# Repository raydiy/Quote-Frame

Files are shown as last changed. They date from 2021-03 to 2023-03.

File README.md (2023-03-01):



# QUOTEFRAME / SPRYGGKLOPPA

This is the complete repository for RAYDIY's QUOTEFRAME (in Germany it's called SPRYGGKLOPPA) project.  
It includes all the 3D printing files and code needed to build this digital quote frame.

More informations here: https://raydiy.de/spryggkloppa-digitaler-spruechekalender/

## Features

- display a set of quotes, sayings, motivationals etc. on an ePaper driven display
- let the displayed text change at an interval you like (every X seconds or minutes or hours or days)
- the quotes are automatically formatted to fit on the screen
- a random font is used to display the quotes
- random font sizes are used to make the quotes more diverse and more appealing
- can be powered with batteries
- config mode is started via touch on a touch sensor
- config mode start a WiFi access point – jus log in an do your changes in the settings

**In config mode you can:**

- add/edit/delete quotes
- export and import the quotes with a JSON format (for backups or bigger edits)
- change the language for the config mode
- change the quote change interval from X seconds to X days

## Updates

#### v1.60 
**Attention:** If you are updating: for this update you will need to re-upload the html files in the data folder to SPIFFS file system.
This will erase your quotes! Because the quotes are also saved in the SPIFFS files system! 
You can export your quotes to JSON **BEFORE** you upload the new code. After the new version is installed you can import this JSON in config mode back into the frame.

- NEW: replaced current fonts with u8g2 font system
- NEW: three Google Fonts converted to u8g2 compatible format and added to project
- NEW: added support for special characters like german ÄÖÜ (due to u8g2)
- NEW: added localization for german language, you can select the language in the settings screen
- ENHANCED: the touch sensor can now be used to restart the frame from config mode back into normal mode
- ENHANCED: fall back font for long quotes. If quotes are longer than 90 symbols, the used font will always be the space saving BebasNeue to ensure it fits on the screen.

#### v1.51 first official release

## 3rd Party Resources

The following third party resources are used. Thank you!

- [GxEPD2 Library by ZinggJM](https://github.com/ZinggJM/GxEPD2)
- [ESP Async WebServer by Hristo Gochkov](https://github.com/me-no-dev/ESPAsyncWebServer.git)
- [ArduinoJson by Benoit Blanchon](https://github.com/bblanchon/ArduinoJson)
- [U8g2_for_Adafruit_GFX by Oliver Kraus](https://github.com/olikraus/U8g2_for_Adafruit_GFX.git)
- [Google Fonts Project](https://fonts.google.com/)
- [mini.css by Angelos Chalaris](https://minicss.org/)

## Project Folders

The following folders are in the download archive:

- **QuoteFrameCode/**: PlatformIO project folder, contains the software for the esp32 microcontroller
- **FreeCAD/**: contains all FreeCAD files for the display mount and the frame
- **Fusion360/**: contains the Fusion 360 archive for the display mount and the frame
- **STL/**: contains the exported ready-to-print STL files from the Fusion 360 project.

## Assembling Instructions (german language only, yet)

Currently there is only a german video instruction. 

ASSEMBLING Video (https://www.youtube.com/watch?v=EmYzOi-3Cw0)

## Materials & Tools I Used for This Project

The following links are Amazon affiliate links. If you use these links I do get a little provision from Amazon. The price for you stays the same!
So if you use these links you help RAYDIY to stay alive – at no costs. Thank you!

* [IKEA RIBBA Frame](https://geni.us/8dEyD)
* [7.5" ePaper Display Waveshare with HAT](https://geni.us/FhP4Ga6)
* [ESP32 unverlötet](https://amzn.to/3Zxoino)
* [Silver wire, 0,6mm](https://geni.us/1WwKYS)
* [Stranded wire silicone insulation](https://amzn.to/3lhfChR)
* [Dupont sockets and connectors](https://geni.us/DBqo)
* [JST-XH sockets and connectors](https://geni.us/hBZhYYS)
* 1 x M2, 4 mm Screw (siehe auch Screw Set)
* 4 x M2, 6 mm Sscre (siehe auch Screw Set)
* [M3 M3 M4 Screw Set](https://geni.us/83MSv)
* [4 LiFePo Accumulators](https://geni.us/QBTAzw)
* [LiFePo Charger](https://geni.us/xk6Eb1)
* [Super glue GEL by Langlauf Schuhbedarf](https://geni.us/cV1n1T)
* [Crimping Pliers, if you create Dupont and JST wires by yourself](https://geni.us/oAjWw)
* [3D-Printer Artillery Sidewinder X1](https://geni.us/zfrg)
* [String Cutter](https://geni.us/kcM2)
* [PCB Board holder](https://geni.us/VXm4)
* [Tweezers](https://geni.us/MKAVfAc)
* [Mini Clamps](https://geni.us/uD2xH)
* Screwdriver
* Armored Tape
* Double sided tape

## Q&A

#### Where do I change the pin settings?
If you want to use a different pin settings, open the file **include/Display.h**  
You will find the pin settings at the top of the file.

#### Are there other configurations I can change?
If you like to, you can change some settings in the file **include/Config.h**

#### How do I export (backup) my quotes?
1. Start config mode and goto import/export page.  
2. Scroll down to the **export section** and press export.  
Now all the quotes get exported to the textarea in a JSON format.
3. Copy this text and paste it somewhere safe.

#### How do I import my quotes?
1. Start config mode and goto import/export page. 
2. In the **import section** paste the JSON code into the textarea.  
If you want to replace all the current quotes on the frame, check the checkbox.  
Otherwise the new set of quotes gets appended.  
3. Press **Import** button to start the import process.

## Support the project ❤️
Do you like this Project?

Please subscribe to [my YouTube chanel](https://www.youtube.com/c/raydiyde) to support this and all follow up projects.

Thank you!

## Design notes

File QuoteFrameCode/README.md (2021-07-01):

# QuoteFrame

This is the PlatformIO code projekt for RAYDIY's SPRYGGKLOPPA quote frame project.  
More informations on https://raydiy.de/spryggkloppa-digitaler-spruechekalender/

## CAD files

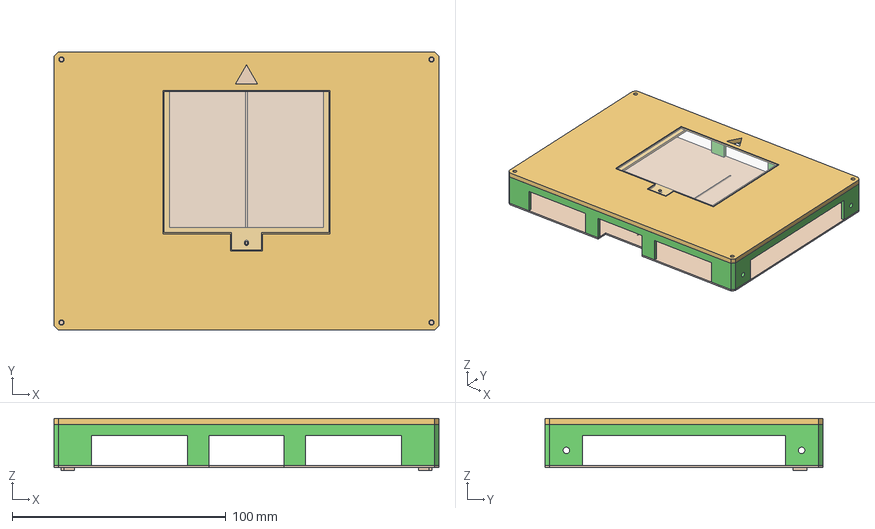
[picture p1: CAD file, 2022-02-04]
FreeCAD/QuoteFrame_SPRYGGKLOPPA.FCStd
180.0 x 130.0 x 24.5 mm
Display_Mount
Frame
Cover_with_Battery_Lid_Hole001
Lid Batteries

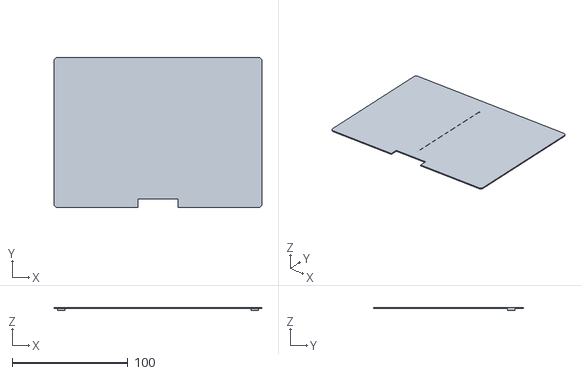
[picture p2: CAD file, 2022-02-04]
STL/Display_Mount.stl
180.0 x 130.0 x 2.50

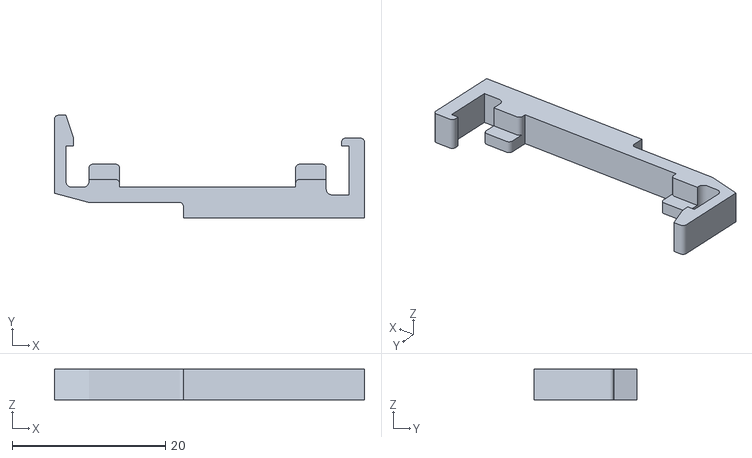
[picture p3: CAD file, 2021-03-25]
STL/PCB Clip ESP v17.stl
40.5 x 13.4 x 4.00

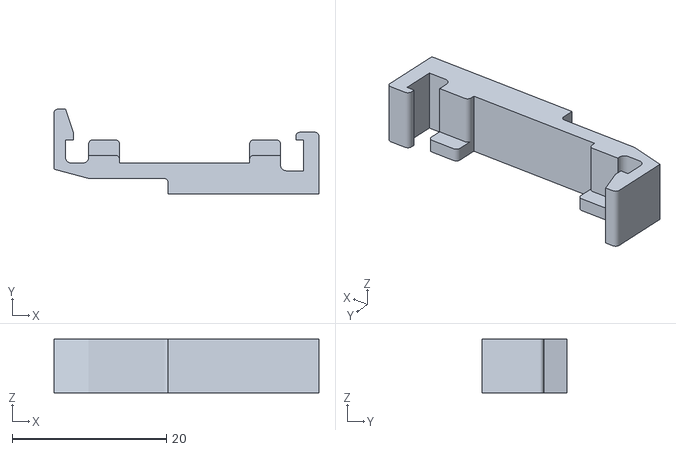
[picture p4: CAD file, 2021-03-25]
STL/PCB Clip ePaper HAT v17.stl
34.4 x 11.0 x 7.00

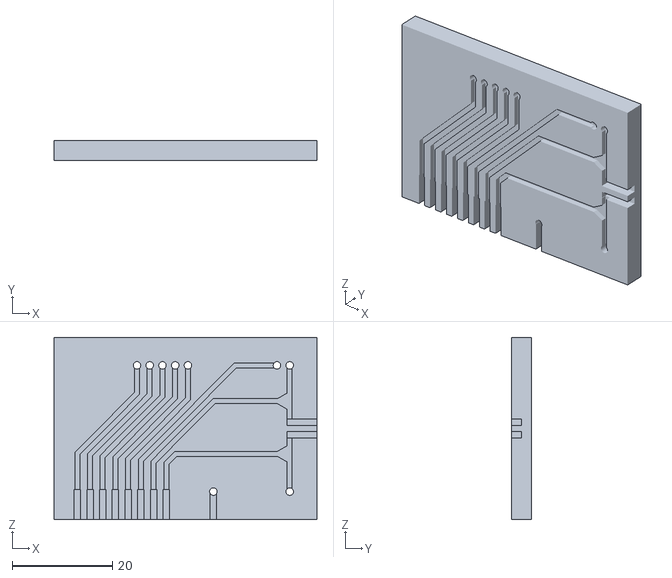
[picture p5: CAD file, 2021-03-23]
STL/PCB_ESP32.stl
52.5 x 4.00 x 36.4

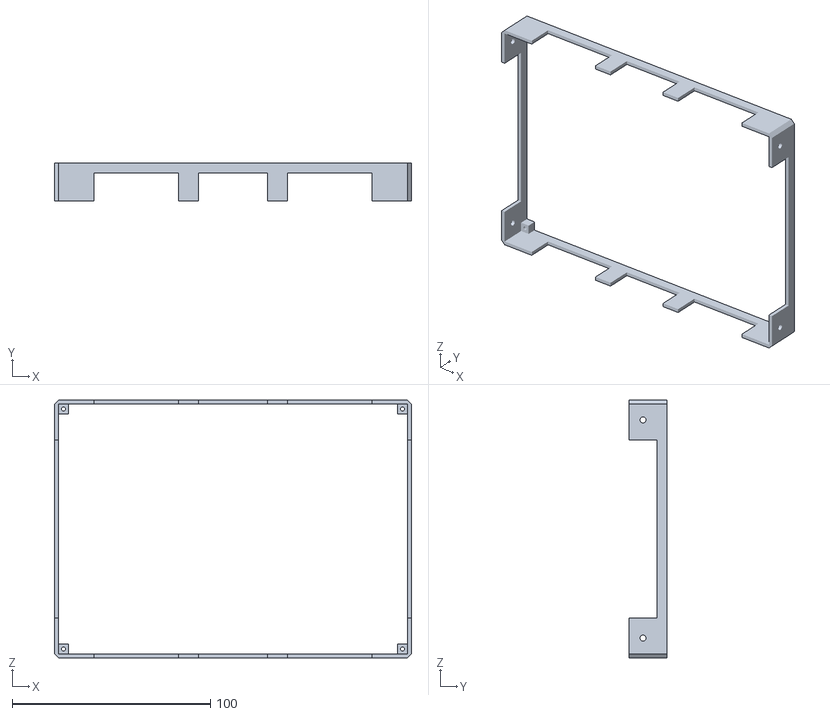
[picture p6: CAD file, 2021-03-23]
STL/Frame.stl
180.0 x 19.0 x 130.0

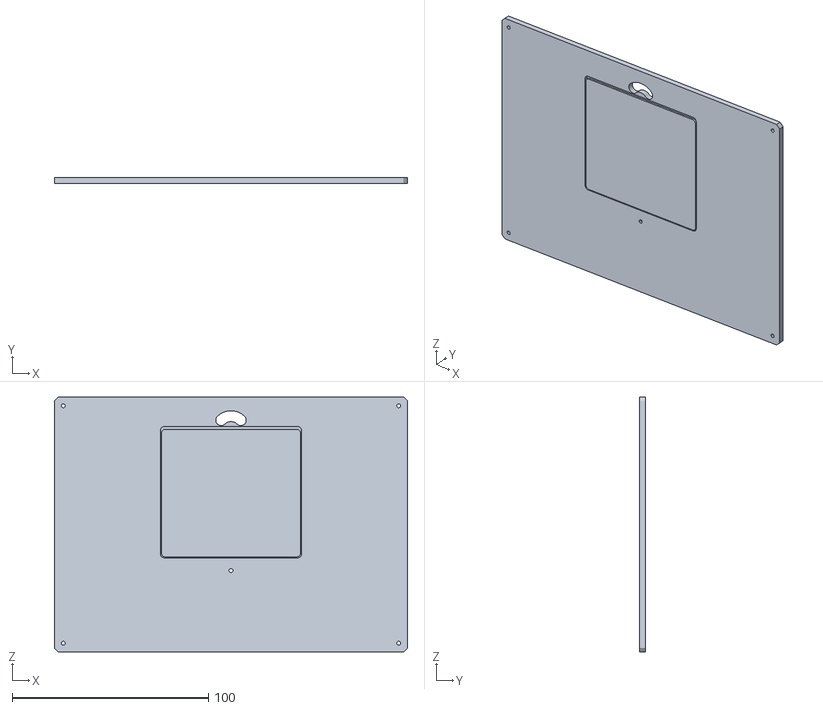
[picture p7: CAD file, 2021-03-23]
STL/Cover.stl
180.0 x 3.00 x 130.0

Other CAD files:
Fusion360/QuoteFrame_SPRYGGKLOPPA v22.f3d

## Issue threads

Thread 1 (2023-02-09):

Touch sensor not working on FireBeetle ESP32-E

kif23, 2023-02-09:
moin..

i have a few problems with the current release 1.64 and the [firebeetle esp32-e](https://wiki.dfrobot.com/FireBeetle_Board_ESP32_E_SKU_DFR0654):

first, i can't upload it to the firebeetle esp32-e according to your instructions:

`Retrieving maximum program size .pio\build\esp32\firmware.elf
Checking size .pio\build\esp32\firmware.elf
Advanced Memory Usage is available via "PlatformIO Home > Project Inspect"
RAM:   [====Error: The program size (1329217 bytes) is greater than maximum allowed (1310720 bytes)
  *** [checkprogsize] Explicit exit, status 1
    ]  35.7% (used 116952 bytes from 327680 bytes)
Flash: [==========]  101.4% (used 1329217 bytes from 1310720 bytes)
=========================================================================================== [FAILED] Took 42.84 seconds `
furthermore the touch mode does not work properly... looks more like a reset/restart... only if i use MODE_CONFIG in the Config.h i get to the AccesPoint and the website.

here are my changes for the firebeetle esp32-e and a waveshare 7.5 inch b/w epaper display:

platformio.ini

[env:esp32]
platform = espressif32
board = esp32dev
board_build.partitions = huge_app.csv
;huge_app.csv sonst kann es nicht auf den firebeetle esp32-e geladen werden?!
framework = arduino
monitor_speed = 115200
lib_ldf_mode = deep+
lib_deps =
	AsyncTCP
	ESP Async WebServer
	ArduinoJson
	zinggjm/GxEPD2@^1.2.14
	SPI
	olikraus/U8g2_for_Adafruit_GFX@^1.8.0
upload_port = COM5
monitor_port = COM5

Config.h

#define TOUCH_THRESHOLD 40                  // Define touch sensitivity. Greater the value, more the sensitivity. 20
#define TOUCH_PIN 4                         // the pin of the touch sensor, default like in YouTube Video is 32. eThing Pulse uses 33. firebeetle esp32-e 4

Display.h

// Connections for firebeetle
static const uint8_t EPD_BUSY = 13;
static const uint8_t EPD_CS   = 2;
static const uint8_t EPD_RST  = 21;
static const uint8_t EPD_DC   = 22;
static const uint8_t EPD_SCK  = 18;
static const uint8_t EPD_MISO = 19;
static const uint8_t EPD_MOSI = 23;

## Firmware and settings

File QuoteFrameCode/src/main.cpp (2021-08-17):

#include <Arduino.h>

// Import required libraries
#include <SPIFFS.h>
#include <ArduinoJson.h>
#include <DNSServer.h>
#include <WiFi.h>
#include <AsyncTCP.h>
#include <ESPAsyncWebServer.h>

#include "Localization.h"
#include "Config.h"
#include "Quotes.h"
#include "Display.h"


// Create DNSServer and AsyncWebServer object on port 80
DNSServer dnsServer;
AsyncWebServer webServer(80);



///////////////////////////////////////////////////////////////
// FUNCTION DECLARATIONS
///////////////////////////////////////////////////////////////

void ConnectToWiFi(const char *STAssid, const char *STApassword);
void HandleRequestDeleteQuote(AsyncWebServerRequest *request);
void HandleRequestEditQuote(AsyncWebServerRequest *request);
void HandleRequestSaveQuote(AsyncWebServerRequest *request);
void HandleRequestReboot(AsyncWebServerRequest *request);
void HandleRequestSettings(AsyncWebServerRequest *request);
void HandleRequestImExport(AsyncWebServerRequest *request);
void DeepSleep_Begin();
void Touch_Callback();
void DeepSleep_PrintWakeupReason();
void DeepSleep_PrintWakeupTouchpad();
void DebugPrintRequestParameter(AsyncWebServerRequest *request);
bool InitWiFiAccessPoint();
void TouchEndConfigMode_Callback();
void FillTouchValuesArray(int value);
int MadianFromArray(int* array, int size);
void PrintArray(int* arr, int size);


// Replaces placeholder with button section in your web page
String processor(const String& var)
{
    //Serial.println("processor()");

    if(var == "HTMLHEAD")
    {
        String q = "";
        q += "<title>" + String(Loca::S(STR_QUOTEFRAME)) + "</title>";
        q += "<meta name=\"viewport\" content=\"width=device-width, initial-scale=1\">";
        q += "<meta http-equiv=\"content-type\" content=\"text/html; charset=utf-8\">";
        q += "<link rel=\"icon\" href=\"data:,\">";
        q += "<link rel=\"stylesheet\" type=\"text/css\" href=\"mini-default.min.css\">";
        return q;
    }
    else if(var == "MENU")
    {
        String q = "";
        q += "<header class=\"sticky\">";
        q += "<a class=\"logo\" href=\"/\">" + String(Loca::S(STR_QUOTEFRAME)) + "</a>";
        q += "<a class=\"button col-sm col-md\" href=\"/new\">&#10133;</a>";
        q += "<a class=\"button col-sm col-md\" href=\"/reboot\">&#x21bb</a>";
        q += "<a class=\"button col-sm col-md\" href=\"/imexport\"><span class=\"icon-upload\"></span></a>";
        q += "<a class=\"button col-sm col-md\" href=\"/settings\">&#9881</a>";

        q += "</header>";
        return q;
    }
    else if(var == "QUOTESTABLE")
    {
        int cntQuotes = Quotes::GetNumberOfQuotes();
        String q = "";

        if ( cntQuotes > 0)
        {
            for (size_t i = 0; i < cntQuotes; i++) 
            { 
                q += "<div class=\"section\">";
                    q += "<div class=\"col-sm-12\"><h3>#" + String(i+1) + "</h3></div>";
                    q += "<div class=\"col-sm-12\"><blockquote cite=\"" + Quotes::q[i].author + "\">" + Quotes::q[i].txt + "</blockquote></div>";
                    q += "<div class=\"col-sm-12\" style=\"text-align: right;\">";
                        q += "<a href=\"/edit?id=" + String(i) + "\" class=\"button small\"><span class=\"icon-edit\"></span></a>";
                        q += "<a href=\"/?delete&id=" + String(i) + "\" class=\"button small\">&#10060;</a>";
                    q += "</div>"; 
                q += "</div>";
            }
        }
        else
        {
            q += "<h3>" + String(Loca::S(STR_NO_QUOTES_FOUND_1)) + "</h3>";
            q += "<p>" + String(Loca::S(STR_ADD_SOME_QUOTES)) + "</p>";
            q += "<a href=\"/new\" class=\"button primary col-sm\" style=\"text-align: center;\">" + String(Loca::S(STR_ADD_FIRST_QUOTE)) + "</a>";
        }
        return q;
    }
    else if(var == "EXPORTJSON")
    {
        if (EXPORT_TO_JSON)
        {
            EXPORT_TO_JSON = false;
            return Quotes::ExportQuotesToJSONString();
        }else{
            return "";
        }    
    }
    else if(var == "QUOTE")
    {
        return Quotes::q[QUOTEID].txt;
    }
    else if(var == "AUTHOR")
    {
        return Quotes::q[QUOTEID].author;
    }
    else if(var == "ID")
    {
        return String(QUOTEID);
    }

    // SETTINGS PAGE
    else if(var == "SETTINGS_INTERVAL_VALUE")
    {
        if ( Settings::interval_seconds > 0 ) { return String(Settings::interval_seconds); }
        if ( Settings::interval_minutes > 0 ) { return String(Settings::interval_minutes); }
        if ( Settings::interval_hours > 0 ) { return String(Settings::interval_hours); }
        if ( Settings::interval_days > 0 ) { return String(Settings::interval_days); }
    }
    else if(var == "SETTINGS_INTERVAL_SECONDS")
    {
        if ( Settings::interval_seconds > 0 ) { return String("selected"); }
        return String("");
    }
    else if(var == "SETTINGS_INTERVAL_MINUTES")
    {
        if ( Settings::interval_minutes > 0 ) { return String("selected"); }
        return String("");   
    }
    else if(var == "SETTINGS_INTERVAL_HOURS")
    {
        if ( Settings::interval_hours > 0 ) { return String("selected"); }
        return String("");
    }
    else if(var == "SETTINGS_INTERVAL_DAYS")
    {
        if ( Settings::interval_days > 0 ) { return String("selected"); }
        return String("");
    }
    else if(var == "SETTINGS_LANGUAGE_EN")
    {
        if ( Settings::language_id == Loca::LANG_EN ) { return String("checked"); }
        return String("");
    }
    else if(var == "SETTINGS_LANGUAGE_DE")
    {
        if ( Settings::language_id == Loca::LANG_DE ) { return String("checked"); }
        return String("");
    }

    // here we exchange the local strings in the HTML pages

    // index
    else if(var == "STR_QUOTES") { return Loca::S(STR_QUOTES); }

    // settings
    else if(var == "STR_SETTINGS") { return Loca::S(STR_SETTINGS); }
    else if(var == "STR_SELECT_LANG") { return Loca::S(STR_SELECT_LANG); }
    else if(var == "STR_QUOTE_INTERVAL") { return Loca::S(STR_QUOTE_INTERVAL); }
    else if(var == "STR_SECONDS") { return Loca::S(STR_SECONDS); }
    else if(var == "STR_MINUTES") { return Loca::S(STR_MINUTES); }
    else if(var == "STR_HOURS") { return Loca::S(STR_HOURS); }
    else if(var == "STR_DAYS") { return Loca::S(STR_DAYS); }
    else if(var == "STR_SAVE") { return Loca::S(STR_SAVE); }

    // new & edit
    else if(var == "STR_ADD_NEW_QUOTE") { return Loca::S(STR_ADD_NEW_QUOTE); }
    else if(var == "STR_EDIT_QUOTE") { return Loca::S(STR_EDIT_QUOTE); }
    else if(var == "STR_QUOTE") { return Loca::S(STR_QUOTE); }
    else if(var == "STR_NEW_QUOTE_HERE") { return Loca::S(STR_NEW_QUOTE_HERE); }
    else if(var == "STR_NEW_AUTHOR_HERE") { return Loca::S(STR_NEW_AUTHOR_HERE); }

    // import/export
    else if(var == "STR_IMPORT_QUOTES") { return Loca::S(STR_IMPORT_QUOTES); }
    else if(var == "STR_JSON_CODE_HERE") { return Loca::S(STR_JSON_CODE_HERE); }
    else if(var == "STR_REPLACE_ALL_QUOTES") { return Loca::S(STR_REPLACE_ALL_QUOTES); }
    else if(var == "STR_EXPORT_QUOTES") { return Loca::S(STR_EXPORT_QUOTES); }

    // save
    else if(var == "STR_QUOTE_SAVED") { return Loca::S(STR_QUOTE_SAVED); }

    return String();
}


class CaptiveRequestHandler : public AsyncWebHandler 
{
    public:
    CaptiveRequestHandler() 
    {
        // Route for root / web page
        webServer.on("/", HTTP_ANY, [](AsyncWebServerRequest *request){
            HandleRequestDeleteQuote(request);
            request->send(SPIFFS, "/index.html", String(), false, processor);
        });

        // Route for /edit web page
        webServer.on("/edit", HTTP_ANY, [](AsyncWebServerRequest *request){
            HandleRequestEditQuote(request);
            request->send(SPIFFS, "/edit.html", String(), false, processor);
        });

        // Route for /new web page
        webServer.on("/new", HTTP_ANY, [](AsyncWebServerRequest *request){
            request->send(SPIFFS, "/new.html", String(), false, processor);
        });

        // Route for /save web page
        webServer.on("/save", HTTP_ANY, [](AsyncWebServerRequest *request){
            HandleRequestSaveQuote(request);
            request->send(SPIFFS, "/save.html", String(), false, processor);
        });

        // Route for /imexport web page
        webServer.on("/imexport", HTTP_ANY, [](AsyncWebServerRequest *request){
            HandleRequestImExport(request);
            request->send(SPIFFS, "/imexport.html", String(), false, processor);
        });

        // Route for /reboot web page
        webServer.on("/reboot", HTTP_ANY, [](AsyncWebServerRequest *request){
            HandleRequestReboot(request);
            request->send(SPIFFS, "/index.html", String(), false, processor);
        });

        // Route for /settings web page
        webServer.on("/settings", HTTP_ANY, [](AsyncWebServerRequest *request){
            HandleRequestSettings(request);
            request->send(SPIFFS, "/settings.html", String(), false, processor);
        });

        // Route to load mini-default.min.css file
        webServer.on("/mini-default.min.css", HTTP_GET, [](AsyncWebServerRequest *request){
            request->send(SPIFFS, "/mini-default.min.css", "text/css");
        });
    }
    virtual ~CaptiveRequestHandler() {}

    bool canHandle(AsyncWebServerRequest *request)
    {
        //request->addInterestingHeader("ANY");
        return true;
    }

    void handleRequest(AsyncWebServerRequest *request)
    {
       request->send(SPIFFS, "/hello.html", String(), false);
    }
};


#define TOUCH_ARRAY_SIZE 100
int touch_value_counter = 0;
int touch_values[TOUCH_ARRAY_SIZE];

/**************************************************
* setup()
*/
void setup() {
    // Serial port for debugging purposes
    Serial.begin(115200);
    while(!Serial);

    // Initialize SPIFFS
    Serial.println("main::setup() Initialize SPIFFS ...");
    if(!SPIFFS.begin(true)){
        Serial.println("main::setup() An Error has occurred while mounting SPIFFS");
        return;
    }

    WiFi.disconnect(true);             // that no old information is stored  
    WiFi.mode(WIFI_OFF);               // switch WiFi off  
    delay(1000);                       // short wait to ensure WIFI_OFF  
    WiFi.persistent(false);            // avoid that WiFi-parameters will be stored in persistent memory  


    // Set Canvas size
    Display::SetCanvasSize(58,35,680,450,60);


    // print wake up reasons to console
    DeepSleep_PrintWakeupReason();
    DeepSleep_PrintWakeupTouchpad();

    // Load Settings from SPIFFS
    Settings::LoadFromSPIFFS();

    // Load quotes from SPIFFS
    Quotes::LoadQuotesFromSPIFFS();
    
    delay(100);
    Display::Init();

    // SETTINGS MODE
    if ( MODE == MODE_CONFIG )
    {

        Display::ShowMessage( Loca::S(STR_START_CONFIG_MODE) );
        
        // START ACCESS POINT MODE //////////////////////////////////////////////////
        // Init WiFi Access Point
        bool successWiFi = InitWiFiAccessPoint();

        if (successWiFi)
        {
            Serial.println("main::setup() WiFi started successfully ...");
            Serial.println("main::setup() Start DNS Server ...");

            // Start DNS server for captive portal. Route all requests to the ESP IP address.
            dnsServer.setErrorReplyCode(DNSReplyCode::NoError);
            dnsServer.start(53, "*", WiFi.softAPIP());

            Serial.println("main::setup() Add handler ...");
            webServer.addHandler(new CaptiveRequestHandler()).setFilter(ON_AP_FILTER); //only when requested from AP

            // Start the web server
            delay(1000);
            Serial.println("main::setup() Webserver started.");
            webServer.begin();
        }
        // END ACCESS POINT MODE //////////////////////////////////////////////////
    }

    // Draw Quotes or Config Infos to the display
    Display::Draw();

    // in quote frame mode we start deep sleep
    if ( MODE == MODE_FRAME )
    {
        DeepSleep_Begin();
    }
}


/**************************************************
* loop()
*/
void loop() 
{
    if ( MODE == MODE_CONFIG )
    {
        dnsServer.processNextRequest();

        // get current touch value from touch sensor wire 
        int touch_value = touchRead(TOUCH_PIN); 

        // fill the touch_values array
        FillTouchValuesArray(touch_value);

        // if array is filled create an average median from all values
        if (touch_value_counter == TOUCH_ARRAY_SIZE)
        {
            // create median
            int median_touch_value = MadianFromArray(touch_values, TOUCH_ARRAY_SIZE);
            

            // check for touch pin to restart frame

            //Serial.print("touch_value/median_touch_value/THRESHOLD: ");
            //Serial.print(touch_value);
            //Serial.print("/");
            //Serial.print(median_touch_value);
            //Serial.print("/");
            //Serial.println(TOUCH_THRESHOLD);

            if ( median_touch_value < TOUCH_THRESHOLD )
            {
                Serial.println("TOUCH DETECTED");
                //Serial.print("last_touch_pin_value: ");
                //Serial.println(last_touch_pin_value);
                //PrintArray(touch_values, TOUCH_ARRAY_SIZE);
                //Serial.print("median_touch_value: ");
                //Serial.println(median_touch_value);

                ESP.restart();
            }
        }
    }
}



///////////////////////////////////////////////////////////////
// FUNCTION DEFINITIONS
///////////////////////////////////////////////////////////////


/**************************************************
* FillTouchValuesArray(int value)
* Fills the touch_values array with new values from the touch sensor
* This array is needed to create a moving avaerage to remove spikes from touch sensor
* to prevent fals positiveve touches
*/
void FillTouchValuesArray(int value)
{
    if (touch_value_counter < TOUCH_ARRAY_SIZE)
    {
        touch_values[touch_value_counter] = value;
        touch_value_counter++;
    }
    else
    {
        // copy array to the left without the very first one that gest overwritten
        for(size_t i=0;i<TOUCH_ARRAY_SIZE-1;i++)
        {
            touch_values[i] = touch_values[i+1]; //move all elements to the left except first one
        }

        // insert new value to the last array element
        touch_values[TOUCH_ARRAY_SIZE-1] = value;
    }
}


/**************************************************
* MadianFromArray(int* arr, int size)
* Creates a median average from an int array
*/
int MadianFromArray(int* arr, int size)
{
    // create median
    int median = 0;
    for (size_t i = 0; i < size; i++)
    {
        median += arr[i];
    }
    median = median/size;
    
    return median;
}


/**************************************************
* PrintArray(int* arr, int size)
* Prints an integer Array to console
*/
void PrintArray(int* arr, int size)
{
    Serial.println( "PrintArray() ---------------" );

    for(size_t i=0;i<size;i++)
    {
        Serial.print(i);
        Serial.print(": ");
        Serial.println( arr[i] );
    }
}


/**************************************************
* HandleRequestImExport(AsyncWebServerRequest *request)
*/
void HandleRequestImExport(AsyncWebServerRequest *request)
{
    // check if a export param is sent via GET
    // if yes, we set the EXPORT_TO_JSON bool to true
    // EXPORT_TO_JSON bool is used in processor() function to export the quotes 
    if (request->hasParam("export")) 
    {
        Serial.println("HandleRequestImExport() EXPORT");
        EXPORT_TO_JSON = true;
    }

    // check if a import param is sent via POST
    // if yes, import param contains the json code for import
    // get the json code add the quotes to QUOTES
    else if (request->hasParam("import", true)) 
    {
        Serial.println("HandleRequestImExport() IMPORT");
        
        DebugPrintRequestParameter(request);

        String importJSON = request->getParam("import", true)->value();
        //Serial.println(importJSON);

        if (request->hasParam("replace", true))
        {
            Quotes::ImportQuotesFromJSONString(importJSON, true);
        }else{
            Quotes::ImportQuotesFromJSONString(importJSON, false);
        }

        Quotes::ResetQuoteCounter();
        Quotes::SaveQuotesToSPIFFS();

        // immediate redirect to home 
        request->redirect("/");
    }
}


/**************************************************
* HandleRequestDeleteQuote(AsyncWebServerRequest *request)
*/
void HandleRequestDeleteQuote(AsyncWebServerRequest *request)
{
    // check if a delete param is sent via GET
    // if yes, check for a quote id parameter and delete that wuote
    if (request->hasParam("delete")) 
    {
        Serial.println("main::HandleRequestDeleteQuote()");

        uint16_t quoteIDtoDelete = request->getParam("id")->value().toInt();
        Quotes::DeleteQuote(quoteIDtoDelete);

        Serial.println("DELETE QUOTE: ");
        Serial.println(quoteIDtoDelete);

        // immediate redirect to home 
        request->redirect("/");
    }
}


/**************************************************
* HandleRequestReboot(AsyncWebServerRequest *request)
*/
void HandleRequestReboot(AsyncWebServerRequest *request)
{
    Serial.println("HandleRequestReboot()");

    // immediate redirect to home 
    request->redirect("/");
    delay(1000);
    ESP.restart();
}

/**************************************************
* HandleRequestSettings(AsyncWebServerRequest *request)
*/
void HandleRequestSettings(AsyncWebServerRequest *request)
{
    Serial.println("main::HandleRequestSettings()");

    if (request->hasParam("save", true)) 
    {
        Serial.println("Save settings ...");

        // reset all intervall values to 0
        Settings::interval_seconds = 0;
        Settings::interval_minutes = 0;
        Settings::interval_hours = 0;
        Settings::interval_days = 0;
    
        // get the intervall value from the form
        int value = request->getParam("interval_value", true)->value().toInt();
    
        if ( request->getParam("interval_unit", true)->value().toInt() == 0 ){ Settings::interval_seconds = value; }
        else if ( request->getParam("interval_unit", true)->value().toInt() == 1 ){ Settings::interval_minutes = value; }
        else if ( request->getParam("interval_unit", true)->value().toInt() == 2 ){ Settings::interval_hours = value; }
        else if ( request->getParam("interval_unit", true)->value().toInt() == 3 ){ Settings::interval_days = value; }

        // gte the language ID
        Settings::language_id = request->getParam("language_value", true)->value().toInt();
        Loca::setLanguage( Settings::language_id );

        // Save to SPIFFS
        Settings::SaveToSPIFFS();

        // immediate redirect to home 
        request->redirect("/");
    }else{
        Serial.println("no save");
    }
}

/**************************************************
* HandleRequestEditQuote(AsyncWebServerRequest *request)
*/
void HandleRequestEditQuote(AsyncWebServerRequest *request)
{
    Serial.println("main::HandleRequestEditQuote()");

    if (request->hasParam("id")) 
    {
        if ( request->getParam("id")->value() == "new" )
        {
            Serial.println("ADD NEW QUOTE");
        }
        else
        {
            QUOTEID = request->getParam("id")->value().toInt();
            Serial.println("EDIT QUOTE");
            Serial.print("QUOTEID set to: ");
            Serial.println(QUOTEID);
        }
    }else{
        Serial.println("No quote id found.");
    }
}


/**************************************************
* HandleRequestSaveQuote(AsyncWebServerRequest *request)
*/
void HandleRequestSaveQuote(AsyncWebServerRequest *request)
{
    Serial.println("main::HandleRequestSaveQuote()");

    String quoteText;
    String quoteAuthor;
    bool isNew = false;

    // if a quote text is sent
    if (request->hasParam("quote", true)) 
    {
        // if a new parameter is sent we add a new quote
        if (request->hasParam("new", true)) 
        {
            QUOTEID = Quotes::GetNextFreeQuoteID();
            isNew = true;
        
            Serial.print("New QUOTEID is: ");
            Serial.println(QUOTEID);
        }

        // if no new parameter is sent we edit an existing quote
        else 
        {
            QUOTEID = request->getParam("id", true)->value().toInt();
            Serial.print("QUOTEID is: ");
            Serial.println(QUOTEID);
        }

        // get the quote text
        quoteText = request->getParam("quote", true)->value();

        // if quote text is not empty
        if ( !quoteText.isEmpty() )
        {
            // check if an author text is sent
            if (request->hasParam("author", true)) 
            {
                quoteAuthor = request->getParam("author", true)->value();
            }

            Quotes::q[QUOTEID].txt = quoteText;
            Quotes::q[QUOTEID].author = quoteAuthor;

            if ( isNew ){ Quotes::ResetQuoteCounter(); }
            Quotes::SaveQuotesToSPIFFS();

            // immediatley redirect
            // if you comment the following line, the user
            // gets a Saved Quote page displayed, where he adas to click OK
            // before the returning to home
            request->redirect("/");
        }
        else 
        {
            Serial.println("Quote text is empty - ABORT");
            request->redirect("/");
        }
    }
}
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

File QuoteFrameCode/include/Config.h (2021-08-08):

// Here you can configure some default values

#define MODE_FRAME 0                        // mode 0 is normal quotes mode
#define MODE_CONFIG 1                       // mode 1 is config mode

#define TOUCH_THRESHOLD 40                  // Define touch sensitivity. Greater the value, more the sensitivity. 20
#define TOUCH_PIN 32                        // the pin of the touch sensor, default like in YouTube Video is 32. eThing Pulse uses 33.
#define SCREEN_ROTATION 0                   // if for some reasons you want to rotate the display, use 0 or 2


const char *AP_SSID     = "QuoteFrame";     // the SSID of the gateway
const char *AP_PASSWORD = "12345678";       // tha password of the gateway
uint16_t QUOTEID        = 0;                // a global qupote id use by the setings to form for deleting and editing quotes
uint16_t LASTQUOTEID    = 0;                // the last quote id that has been displayed
bool EXPORT_TO_JSON     = false;            // needed for the JSON export in config mode
uint TIME_TO_DEEPSLEEP  = 120;              // in seconds, how long after a new quote gets loaded. 60*60*24 would be once per day. 60 would be every minute
uint8_t MODE            = MODE_FRAME;       // MODE does contain the current active mode, per default the fraem starts in MODE_FRAME
uint8_t LANGUAGE        = 0;                // Current Langauge ID. 0: EN, 1: DE

IPAddress local_IP(192,168,4,1);            // the default IP adress & subnet mask you find the gateway at 
IPAddress gateway(192,168,4,1);
IPAddress subnet(255,255,255,0);



//////////////////////////////////////////////////////////////////////////////////////////////////////////
// CLASS DECLARATION
//////////////////////////////////////////////////////////////////////////////////////////////////////////


class Settings 
{
    public:
        static uint16_t interval_seconds;
        static uint16_t interval_minutes;
        static uint16_t interval_hours;
        static uint16_t interval_days;
        static byte inactivity_restart;
        static uint16_t last_quote_id;
        static uint8_t language_id;

        static void SaveToSPIFFS();
        static void LoadFromSPIFFS();
        static uint GetIntervallInSeconds();
};


//////////////////////////////////////////////////////////////////////////////////////////////////////////
// CLASS DEFINITIONS
//////////////////////////////////////////////////////////////////////////////////////////////////////////

// default values

uint16_t Settings::interval_seconds = 0;
uint16_t Settings::interval_minutes = 2;
uint16_t Settings::interval_hours = 0;
uint16_t Settings::interval_days = 0;
byte Settings::inactivity_restart = 5;
uint16_t Settings::last_quote_id = 0;
uint8_t Settings::language_id = Loca::LANG_EN;


/**************************************************
* SaveToSPIFFS()
* The current Settings gets converted to a JSON string which gets written 
* to SPIFFS
*/
void Settings::SaveToSPIFFS()
{
    // write Settings to SPIFFS file stream

    Serial.println(F("Settings::SaveToSPIFFS()"));

    StaticJsonDocument<128> doc;

    doc["interval_seconds"]     = Settings::interval_seconds;
    doc["interval_minutes"]     = Settings::interval_minutes;
    doc["interval_hours"]       = Settings::interval_hours;
    doc["interval_days"]        = Settings::interval_days;
    doc["inactivity_restart"]   = Settings::inactivity_restart;
    doc["last_quote_id"]        = Settings::last_quote_id;
    doc["language_id"]          = Settings::language_id;

    // serialize the object and send the result to Serial
    serializeJsonPretty(doc, Serial);
    Serial.println(F(""));

    File fileSettings = SPIFFS.open("/settings.json", "w");

    // Serialize JSON to file
    if (serializeJson(doc, fileSettings) == 0) {
        Serial.println(F("Failed to write to file"));
    }
      
    // Close the file
    fileSettings.close();

    Serial.println(F("Settings saved to SPIFFS"));
}
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

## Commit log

2021-03-22 added FreeCAD files to repo added workflow added gitignore
    [Cover.stl, Display_Mount.stl, Frame.stl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]
2021-03-22 made everything parametric using spreadsheet
    [QuoteFrame_SPRYGGKLOPPA.FCStd]
2021-03-23 - added Fusion 360 project archive - added STL folder with exported STLs from Fusion 360 version - updated FreeCAD version
    [Cover.stl, Display_Mount.stl, Frame.stl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]
2021-03-23 added stl file of PCB for ESP 32
    [PCB_ESP32.stl]
2021-03-25 - added PCB Clip for self printed ESP PCB - added PCB for Waveshare ePaper HAT PCB
    [PCB Clip ESP v17.stl, PCB Clip ePaper HAT v17.stl]
2021-07-02 removed quote.count from import/export since it is not used currently
2021-07-07 fixed empty screen if no quote is found
    [main.cpp]
2021-07-09 fixed random quote when two quotes are found
    [Config.h]
2021-08-08 - in config mode: restart per touch sensor in to frame mode
2021-08-08 changed touch pin threshold back to 40
2021-08-17 fixed false positive touch sensor detection in config mode added a moving average to touch touch sensor values to remove spikes that lead to false positive touch detections
    [main.cpp]
2022-02-04 Cover: removef two of the four corners to position the display due too tight measurements
    [Cover.stl, QuoteFrame_SPRYGGKLOPPA.FCStd]
2022-02-05 fixed STL files after I mixed up Cover.stl and Display_Mount.stl
    [Cover.stl, Display_Mount.stl]
